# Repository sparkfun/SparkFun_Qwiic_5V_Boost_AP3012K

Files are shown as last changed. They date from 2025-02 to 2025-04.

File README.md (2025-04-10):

SparkFun Qwiic 5V Boost - AP3012K
========================================

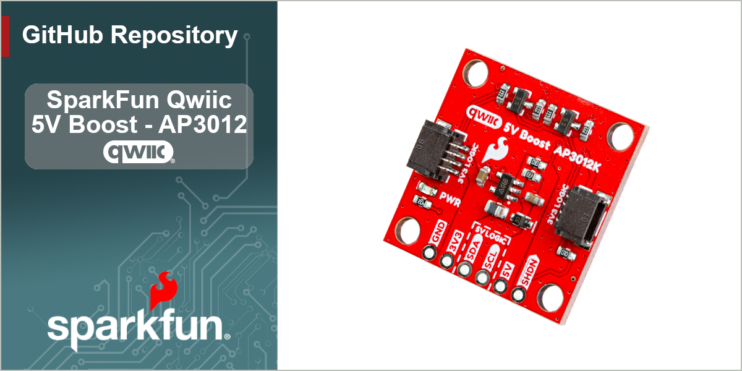
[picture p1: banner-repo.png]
SparkFun Qwiic 5V Boost - AP3012K (https://www.sparkfun.com/sparkfun-qwiic-5v-boost-ap3012k.html)


From its Qwiic connectors, the [SparkFun Qwiic 5V Boost - AP3012K](https://www.sparkfun.com/sparkfun-qwiic-5v-boost-ap3012k.html) converts the **3.3V** logic-level of the I<sup>2</sup>C signals and boosts the **3.3V** power supply; all to **5V** on its [PTH *(plated through-hole)*](https://en.wikipedia.org/wiki/Through-hole_technology) pins. This is handy for connecting any I<sup>2</sup>C device that requires a higher supply voltage for an RGB LED or mechanisms like a DC fan on our air quality sensors:

- [Sensirion SPS30 - Particulate Matter Sensor](https://www.sparkfun.com/particulate-matter-sensor-sps30.html)
- [Sensirion SEN54 - Particle, VOC, Humidity, and Temperature Sensor](https://www.sparkfun.com/particle-voc-humidity-and-temperature-sensor-sen54.html)
- [Sensirion SEN55 - Particle, VOC, NO<sub>x</sub>, Humidity, and Temperature Sensor](https://www.sparkfun.com/sensirion-particle-voc-humidity-and-temperature-sensor-sen55.html)

On the board, we provide `3V3`/`5V` jumpers, which can be used to configure the logic-levels of the I<sup>2</sup>C PTH pins. Therefore, this board can be utilized to connect an I<sup>2</sup>C device that requires any combination of 3.3V/5V for its power and/or signals. Additionally, the [TTL *(transistor–transistor logic)*](https://en.wikipedia.org/wiki/Transistor%E2%80%93transistor_logic) used to convert the logic-levels of the I<sup>2</sup>C signals can also implemented with other types of interfaces; such as a serial bus, similar to our [SparkFun Logic Level Converter - Single Supply](https://www.sparkfun.com/sparkfun-logic-level-converter-single-supply.html).

<hr>

> [!WARNING]
> Soldering is required to connect a 5V I<sup>2</sup>C device to this board.

> [!NOTE]
> The boost circuit on this board is rated to source up to a 100mA at 5V output, with 90% efficiency. However, users should note that this limitation is not only dependent on the load being connected, but also the amount of current that is being sourced to the Qwiic connector system.

Documentation
--------------
- **[Hookup Guide (mkdocs)](http://docs.sparkfun.com/SparkFun_Qwiic_5V_Boost_AP3012K/)** - A hookup guide for the Qwiic 5V Boost - AP3012K, hosted by GitHub pages.<br>
   

  *Need to download or print our hookup guide?*

  - [Print *(Print to PDF)* from Single-Page View](http://docs.sparkfun.com/SparkFun_Qwiic_5V_Boost_AP3012K/print_view)

Repository Contents
-------------------
- **[/docs](/docs/)** - Online documentation files
    - [/assets](/docs/assets/) - Assets files
        - [/3d_model](/docs/assets/3d_model/) - Files for the 3D models
            - [3D CAD Model](/docs/assets/3d_model/cad_model.step) (.step)
        - [/board_files](/docs/assets/board_files/) - Files for the product design
            - [KiCad Design Files](/docs/assets/board_files/kicad_files.zip) (.zip)
            - [Schematic](/docs/assets/board_files/schematic.pdf) (.pdf)
            - [Dimensions](/docs/assets/board_files/dimensions.pdf) (.pdf)
        - [/component_documentation](/docs/assets/component_documentation/) - Datasheets for hardware components
        - [/img/hookup_guide/](/docs/assets/img/hookup_guide/) - Images for hookup guide documentation
- **[/Hardware](/Hardware/)** - Hardware design files (.brd, .sch)
  - **[/Production](/Production/)** - Production files

Product Variants
----------------
- [PRT-28203](https://www.sparkfun.com/sparkfun-qwiic-5v-boost-ap3012k.html) - Initial Release

Version History
---------------
- [v10](https://github.com/sparkfun/SparkFun_Qwiic_5V_Boost_AP3012K/releases/tag/v10) - Initial Release

License Information
-------------------

This product is ***open source***!

Please review the [`LICENSE.md`](./LICENSE.md) file for license information.

If you have any questions or concerns about licensing, please contact technical support on our [SparkFun forums](https://community.sparkfun.com/).

Distributed as-is; no warranty is given.

- Your friends at SparkFun.

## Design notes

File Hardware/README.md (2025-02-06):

SparkFun <PRODUCT NAME> Design Files
=====================================

The .sch and .brd files hare are Eagle CAD schematic and PCB design files from SparkFun Electronics.
A freeware version of Autodesk Eagle can be found [here](https://www.autodesk.com/products/eagle/free-download).

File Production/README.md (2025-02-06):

SparkFun <PRODUCT NAME> Production Files
=========================================

These are the production files SparkFun uses for printing PCBs.

License Information
-------------------
This product is open source! 

The hardware is released under [Creative Commons ShareAlike 4.0 International](https://creativecommons.org/licenses/by-sa/4.0/).

Please use, reuse, and modify these files as you see fit. Please maintain attribution to SparkFun Electronics and release anything derivative under the same license.

Distributed as-is; no warranty is given.

- Your friends at SparkFun.

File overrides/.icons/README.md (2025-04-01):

.icons directory
====================
This folder should contain branding logos for the product documentation

## General Images
- `sfe.svg` - SparkFun flame logo
- `kicad-primary.svg` - Full KiCad logo

## Directory
- `logo` - Other available logos

## SVG Optimizer
- [Remove meta data from svg](https://jakearchibald.github.io/svgomg/)

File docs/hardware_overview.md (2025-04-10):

## :material-folder-cog: Design Files

<!-- Import the component -->
<script type="module" src="https://ajax.googleapis.com/ajax/libs/model-viewer/3.5.0/model-viewer.min.js"></script>

<div class="grid cards desc" markdown>

-   :kicad-primary:{ .enlarge-logo } Design Files

	---

	- :fontawesome-solid-file-pdf: [Schematic](./assets/board_files/schematic.pdf)
	- :material-folder-zip: [KiCad Files](./assets/board_files/kicad_files.zip)
	- :material-rotate-3d: [STEP File](./assets/3d_model/cad_model.step)
	- :fontawesome-solid-file-pdf: [Board Dimensions](./assets/board_files/dimensions.pdf):
		- 1.00" x 1.00" (25.40mm x 25.40mm)

-   <!-- Boxes in tabs -->

	=== "3D Model"
		<center>
		<model-viewer src="../assets/3d_model/web_model.glb" camera-controls poster="../assets/3d_model/poster.png" tone-mapping="neutral" shadow-intensity="1.7" exposure="0.8" environment-image="legacy" shadow-softness="0.7" camera-orbit="3.797e-14deg 35deg 0.07345m" field-of-view="30deg" style="width: 100%; height: 450px;">
		</model-viewer>

		[Download the `*.step` File](./assets/3d_model/cad_model.step "Click download"){ .md-button .md-button--primary width="250px" }

		</center>

		???+ tip "Manipulate 3D Model"
			<center>

			| Controls       | Mouse                    | Touchscreen    |
			| :------------- | :----------------------: | :------------: |
			| Zoom           | Scroll Wheel             | 2-Finger Pinch |
			| Rotate         | ++"Left-Click"++ & Drag  | 1-Finger Drag  |
			| Move/Translate | ++"Right-Click"++ & Drag | 2-Finger Drag  |

			</center>

	=== "Dimensions"
		<center>
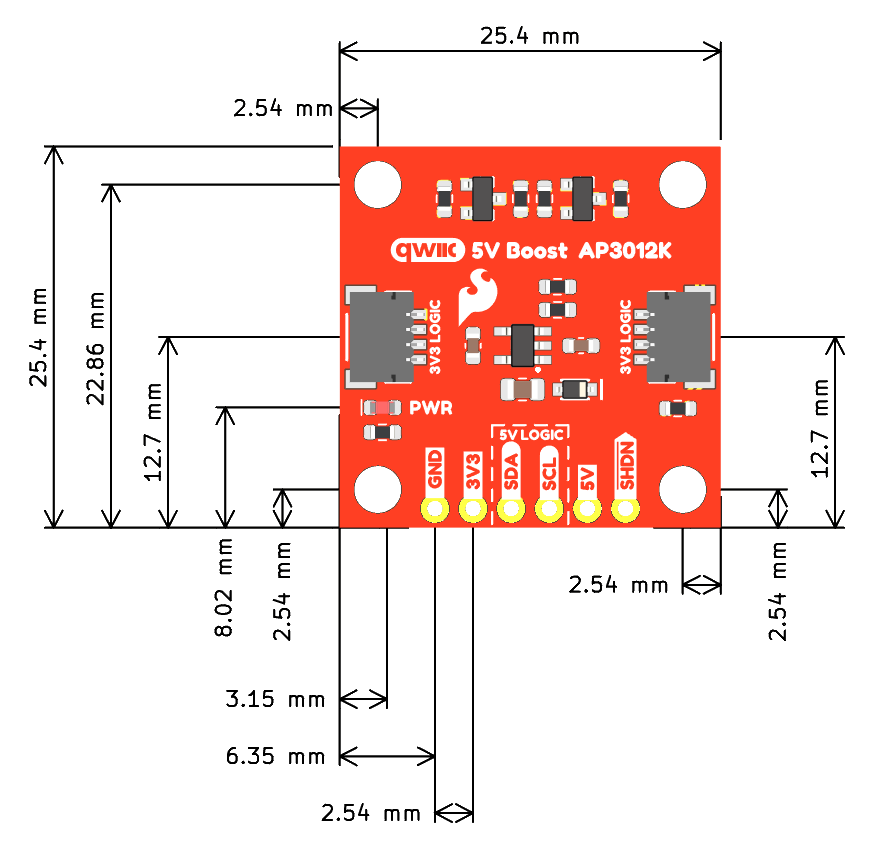
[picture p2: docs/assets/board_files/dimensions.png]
Board Dimensions
		
		<figcaption markdown>
		Dimensions of the Qwiic 5V Boost.
		</figcaption>
		</center>

		???+ tip "Need more measurements?"
			For more information about the board's dimensions, users can download the [KiCad files](./assets/board_files/kicad_files.zip) for this board. These files can be opened in KiCad and additional measurements can be made with the measuring tool.

			!!! info ":octicons-download-16:{ .heart } KiCad - Free Download!"
				KiCad is free, open-source [CAD]("computer-aided design") program for electronics. Click on the button below to download their software. *(\*Users can find out more information about KiCad from their [website](https://www.kicad.org/).)*

				<center>
				[Download :kicad-primary:{ .enlarge-logo }](https://www.kicad.org/download/ "Go to downloads page"){ .md-button .md-button--primary width="250px" }
				</center>

			???+ info ":straight_ruler: Measuring Tool"
				This video demonstrates how to utilize the dimensions tool in KiCad, to include additional measurements:

				<center>
				<article class="video-500px">
				<iframe src="https://www.youtube.com/embed/-eXuD8pkCYw" title="KiCad Dimension Tool" frameborder="0" allow="accelerometer; autoplay; clipboard-write; encrypted-media; gyroscope; picture-in-picture" allowfullscreen></iframe>
				</article>
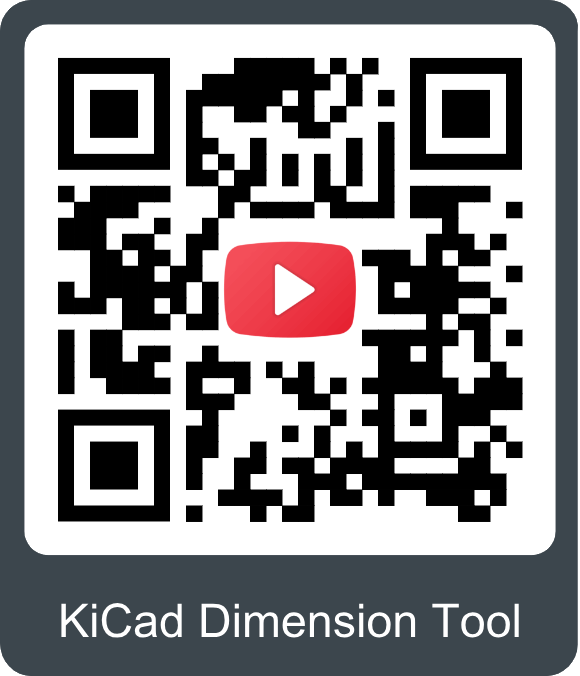
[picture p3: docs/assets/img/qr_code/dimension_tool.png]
QR code to play video
				
				</center>

</div>

## Board Layout

<div class="grid" markdown>

<div markdown>

<figure markdown>
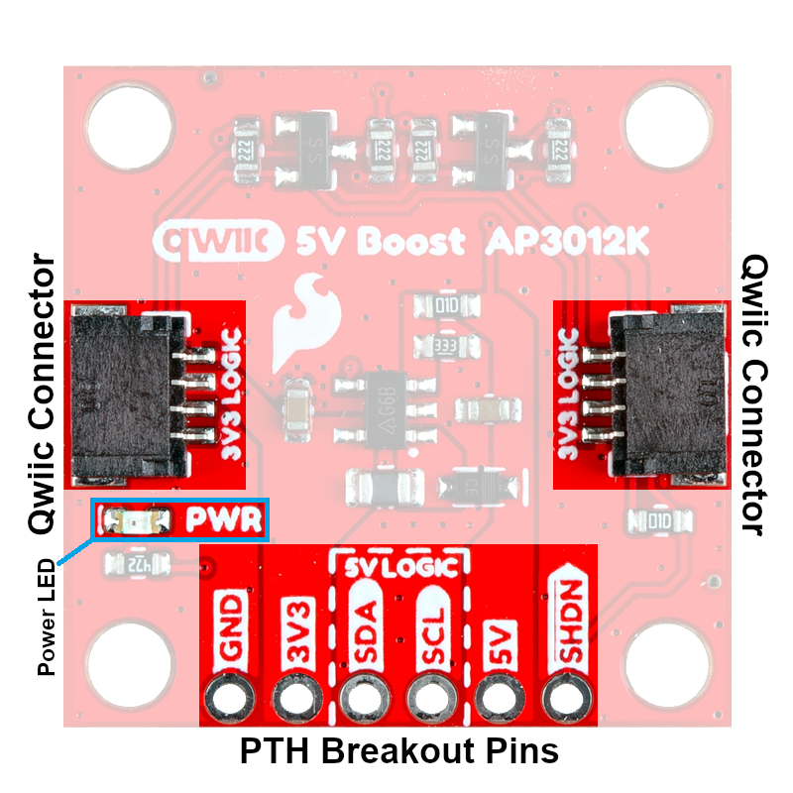
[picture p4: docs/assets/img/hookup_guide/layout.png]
Layout

<figcaption markdown>Layout of the major components on the Qwiic 5V Boost.</figcaption>
</figure>

</div>

<div markdown>

The Qwiic 5V Boost has the following features:

1. **[PTH Breakout Pins](#breakout-pins)**
:	A set of six 0.1" pitch [PTH](https://en.wikipedia.org/wiki/Through-hole_technology "Plated Through Hole") pins that breakout the boosted power and converted [TTL](https://en.wikipedia.org/wiki/Transistor%E2%80%93transistor_logic "Transistor–Transistor Logic") signals of the I^2^C bus; and a control pin for the boost converter.
1. **[Qwiic Connectors](#qwiic-connectors)**
:	The primary interfaces for the Qwiic 5V Boost, these are pass-through connectors for the I^2^C bus.
1. **[`PWR` LED](#led)**
:	A red indication LED for when the board is supplied with 3.3V.

</div>

</div>

## Breakout Pins
The [PTH](https://en.wikipedia.org/wiki/Through-hole_technology "Plated Through Hole") pins of the Qwiic 5V Boost breakout: the 3.3V power supply from the [Qwiic connectors](#qwiic-connectors) that supplies power to the AP3012, the boosted 5V power output from the AP3012, a control pin to disable the AP3012, and the converted 5V, logic-level I^2^C signals from the [Qwiic connectors](#qwiic-connectors).

<div class="grid" markdown>

<div markdown>

<figure markdown>
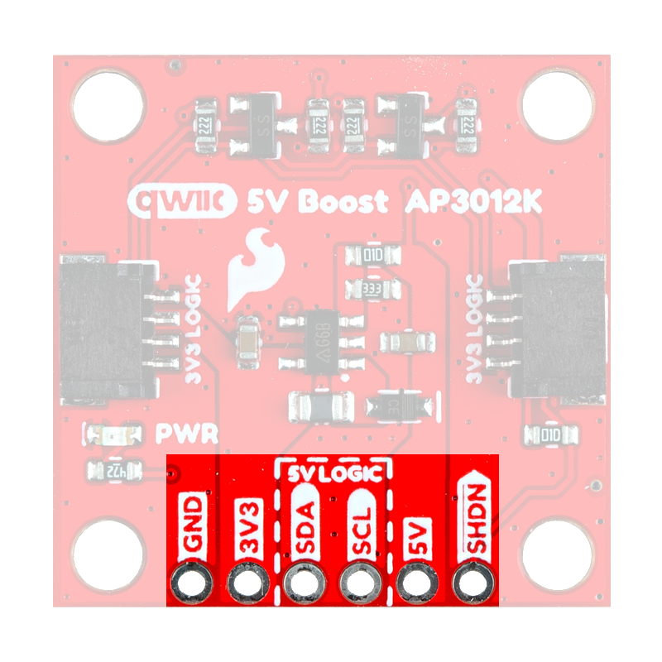
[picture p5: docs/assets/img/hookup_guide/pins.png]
Flipped pins

<figcaption markdown>Pin connections between the top and bottom of the Qwiic 5V Boost.</figcaption>
</figure>

</div>

<div markdown>

`GND`
:	The common ground or the 0V reference for the voltage supplies.

`3V3`
:	The same 3.3V operating power for the Qwiic connectors.

`SDA`/`SCL`
:	The converted [TTL](https://en.wikipedia.org/wiki/Transistor%E2%80%93transistor_logic "Transistor–Transistor Logic") signals of the I^2^C pins from the [Qwiic connectors](#qwiic-connectors); their converted logic-level is controlled by the `3V3`/`5V` [jumpers](#jumpers).

`5V`
:	The boost 5V power output from the AP3012 boost converter, which is rated up to ~100mA load.

<span style="text-decoration:overline">`SHDN`</span>
:	The control signal for AP3012 boost converter; pull `LOW` to disable the IC.

</div>

</div>

!!! info "I/O Configurations"
	With the [`3V3`/`5V` jumpers](#jumpers) to configure the logic-levels of the I^2^C [PTH](https://en.wikipedia.org/wiki/Through-hole_technology "Plated Through Hole") pins, users can convert the power and logic-levels of the Qwiic connector to any combination of 3.3V and/or 5V on the PTH pins:

	<center>

	<table markdown>
	<tr>
	<th>Output Power</th>
	<td>5V</td>
	<td>5V</td>
	<td>3.3V</td>
	</tr>
	<tr markdown>
	<th markdown>I^2^C Logic-Level</th>
	<td>3.3V</td>
	<td>5V</td>
	<td>5V</td>
	</tr>
	</table>

	</center>

	*By default, the pins are configured to a 5V logic-level.*

???+ danger "Maximum Load Current"
	We recommend a maximum load current of ~100mA from the `5V` output supply voltage from the AP3012 boost converter.

	The boosted supply voltage of the boost converter will begin to drop as the current draw from the load increases. We found that for a boosted 5V output from a 3.3V input voltage, there is an inflection point around **100mA** where the boosted voltage begins to drop off significantly.

	<center>

	| Load Current | Boosted Voltage |
	| :----------: | :-------------: |
	| 10mA | 4.92V |
	| 20mA | 4.91V |
	| 75mA | 4.90V |
	| 100mA | 4.89V |
	| 150mA | 4.87V |
	| 200mA | 4.65V |

	</center>

	!!! info
		This limitation is driven by the current load and supply current for the Qwiic connect system. It is not dictated by the junction temperature of the AP3012.

## Qwiic Connectors
Qwiic connectors are provided for users to seamlessly integrate with [SparkFun's Qwiic Ecosystem](https://www.sparkfun.com/qwiic). These are pass-through connectors that operate at the standard 3.3V operating voltage and logic-levels.

<figure markdown>
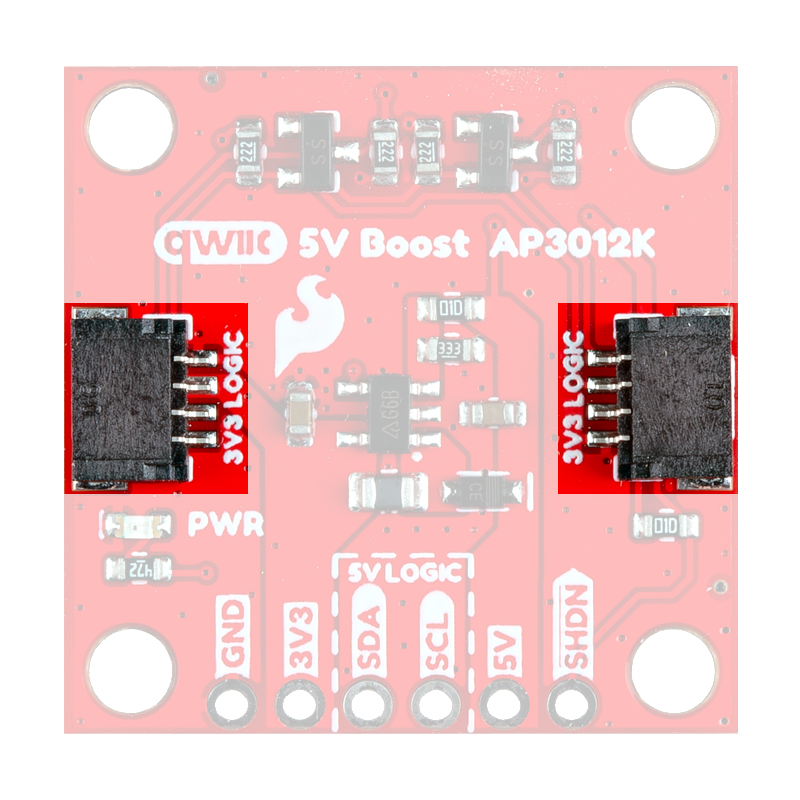
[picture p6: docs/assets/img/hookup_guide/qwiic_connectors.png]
Qwiic connectors

<figcaption markdown>Qwiic connectors on the Qwiic 5V Boost.</figcaption>
</figure>

???+ tip "What is Qwiic?"

	<div class="grid" markdown>

	<div markdown>

	<!-- Qwiic Banner -->
	<center>
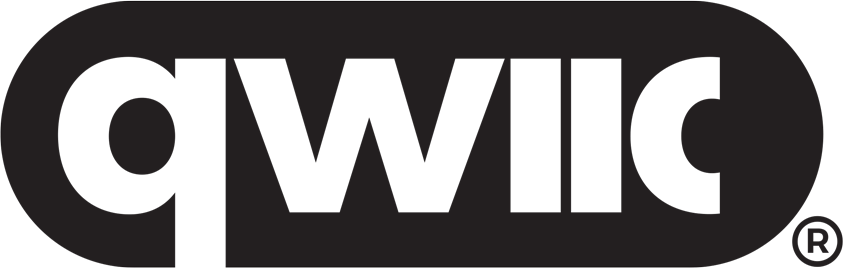
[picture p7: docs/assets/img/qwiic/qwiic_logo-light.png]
Qwiic Logo - light theme (https://www.sparkfun.com/qwiic)
	
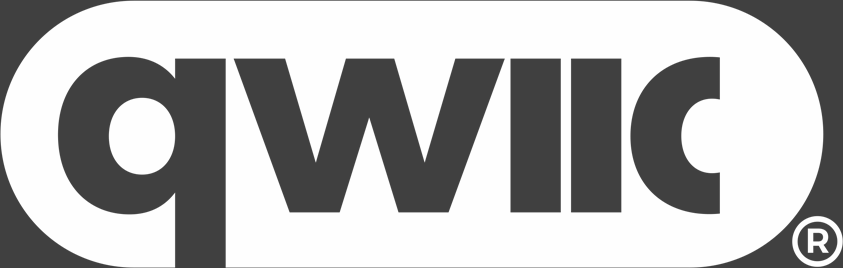
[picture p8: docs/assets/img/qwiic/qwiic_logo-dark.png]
Qwiic Logo - dark theme (https://www.sparkfun.com/qwiic)
	
	</center>

	---

	The [Qwiic connect system](https://www.sparkfun.com/qwiic) is a solderless, polarized connection system that allows users to seamlessly daisy chain I^2^C boards together. Play the video, to learn more about the Qwiic connect system or click on the banner above to learn more about [Qwiic products](https://www.sparkfun.com/qwiic).

	</div>

	<div style="max-height=400px;" markdown>

	<center>
	<div class="video-container">
	<iframe src="https://www.youtube.com/embed/x0RDEHqFIF8" title="SparkFun's Qwiic Connect System" frameborder="0" allow="accelerometer; encrypted-media; gyroscope; picture-in-picture" allowfullscreen></iframe>
	</div>
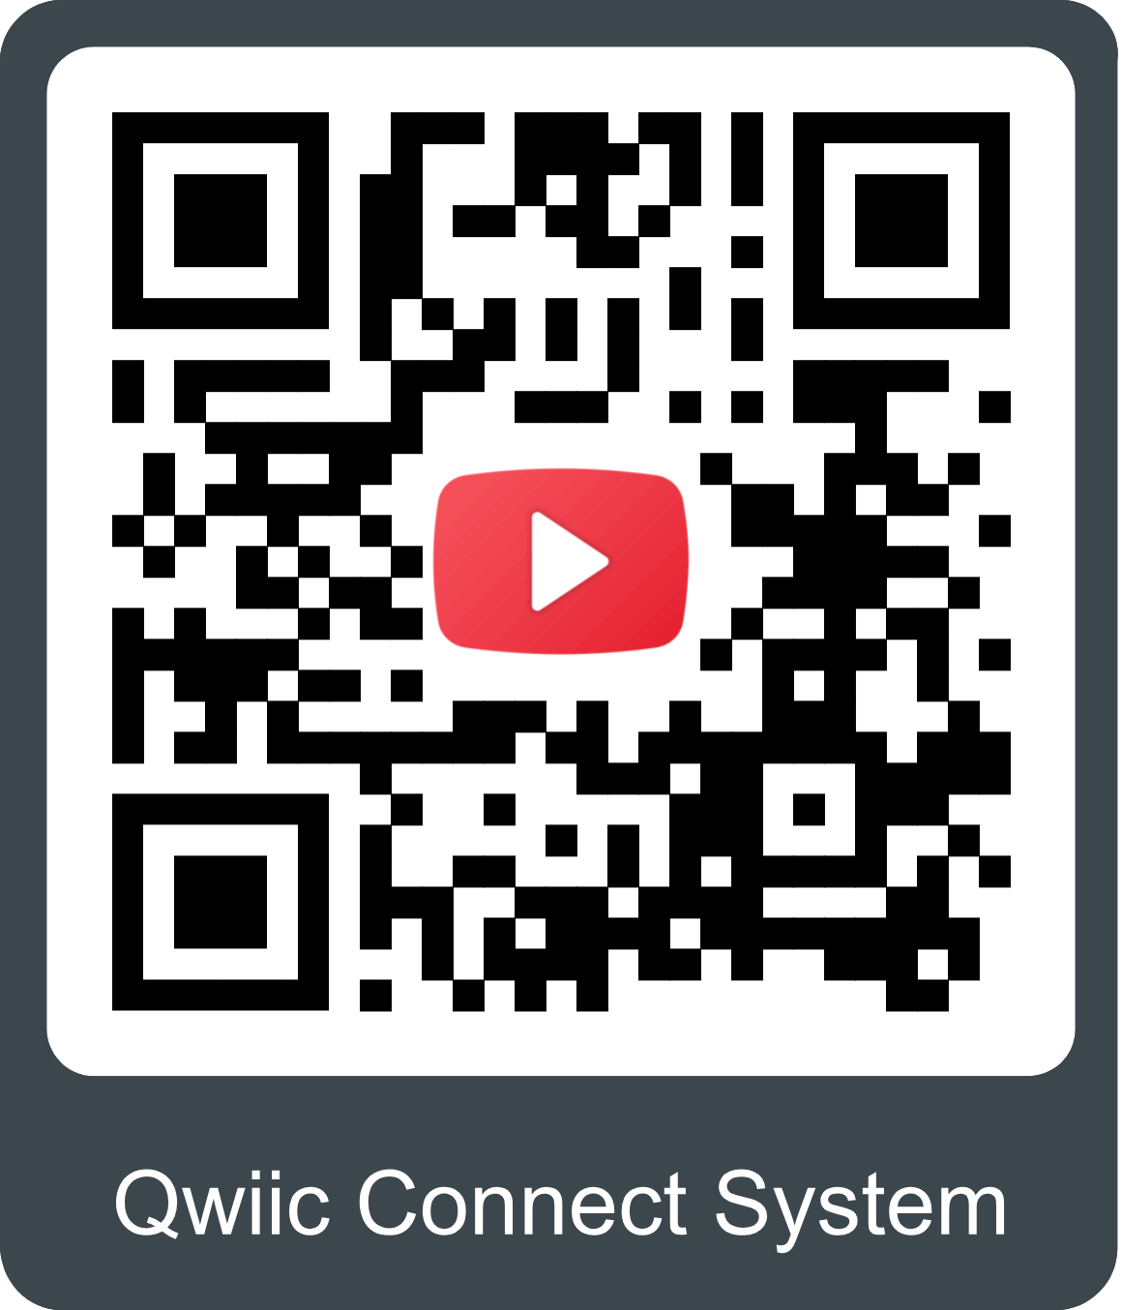
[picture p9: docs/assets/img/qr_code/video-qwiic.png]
QR code to instructional video
	
	</center>

	</div>

	</div>

	!!! info "Features of the Qwiic System"

		=== "No Soldering"

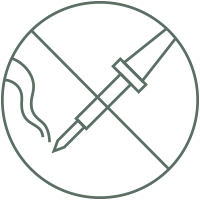
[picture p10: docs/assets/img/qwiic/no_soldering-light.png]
no soldering - light theme
			
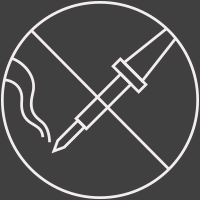
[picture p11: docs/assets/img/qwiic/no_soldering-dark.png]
no soldering - dark theme
			

			Qwiic cables (4-pin JST) plug easily from development boards to sensors, shields, accessory boards and more, making easy work of setting up a new prototype.

		=== "Polarized Connector"

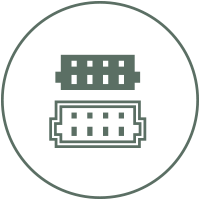
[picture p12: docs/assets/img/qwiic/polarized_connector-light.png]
polarized connector - light theme
			
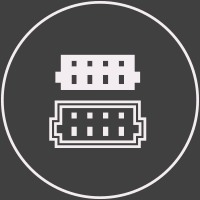
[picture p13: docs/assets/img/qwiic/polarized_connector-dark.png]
polarized connector - dark theme
			

			There's no need to worry about accidentally swapping the `SDA` and `SCL` wires on your breadboard. The Qwiic connector is polarized so you know you’ll have it wired correctly every time.

			The part numbers for the PCB connector is `SM04B-SRSS` ([Datasheet](https://cdn.sparkfun.com/assets/parts/1/2/2/8/9/Qwiic_Connector_Datasheet.pdf)) and the mating connector on the cables is `SHR04V-S-B`; or an equivalent *1mm pitch, 4-pin JST connection*.

		=== "Daisy Chain-able"

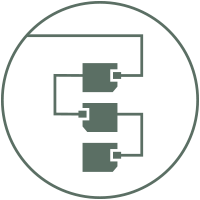
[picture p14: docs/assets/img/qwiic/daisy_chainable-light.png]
daisy chainable - light theme
			
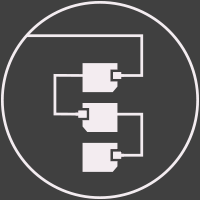
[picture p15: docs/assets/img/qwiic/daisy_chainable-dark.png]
daisy chainable - dark theme
			

			It’s time to leverage the power of the I^2^C bus! Most Qwiic boards will have two or more connectors on them, allowing multiple devices to be connected.

## LED
There is a red `PWR` LED to indicate when the Qwiic 5V Boost is powered with 3.3V. The LED can be disabled by cutting the `LED` [jumper](#jumpers).

<figure markdown>
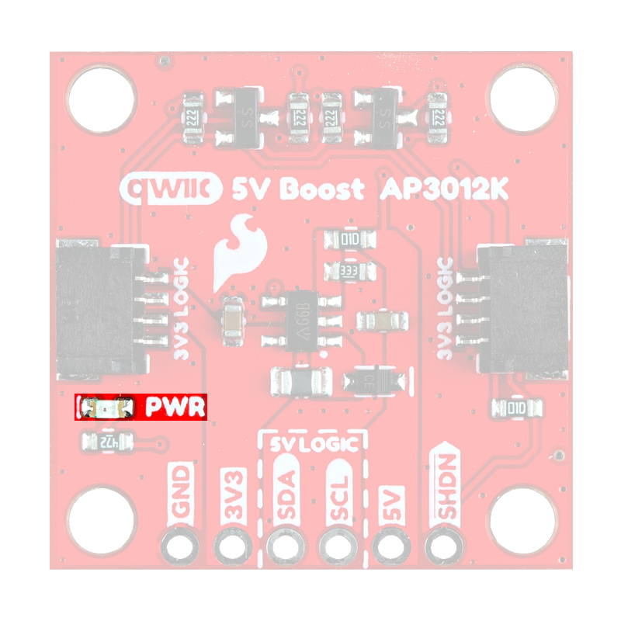
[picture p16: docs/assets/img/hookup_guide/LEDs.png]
LED

<figcaption markdown>The red `PWR` LED the Qwiic 5V Boost.</figcaption>
</figure>

## Jumpers
There are four jumpers on the back of the board that can be used to easily modify the hardware connections on the board.

<div class="grid" markdown>

<div markdown>

<figure markdown>
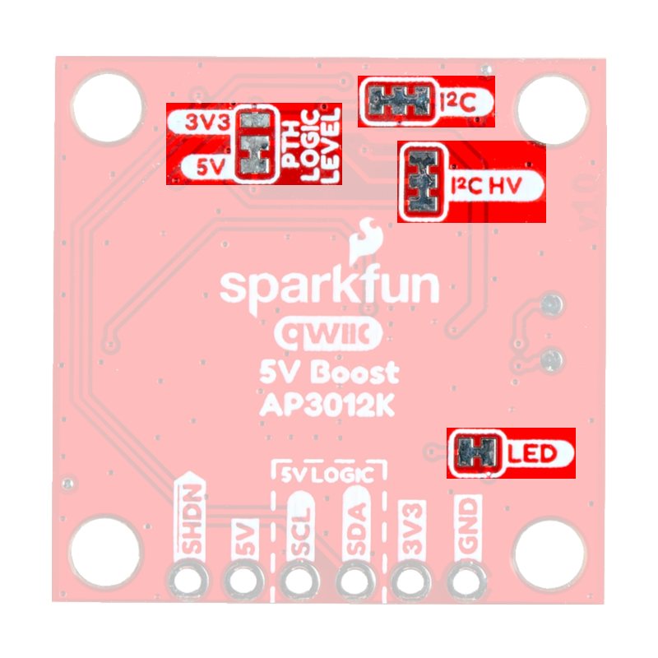
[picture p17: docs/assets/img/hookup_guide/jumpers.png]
Jumpers

<figcaption markdown>The jumpers on the top of the Qwiic 5V Boost.</figcaption>
</figure>

</div>

<div markdown>

`I2C`
:	This jumper can be cut to disconnect the pull-up resistors from the I^2^C pins of Qwiic connectors.

`I2C HV`
:	This jumper can be cut to disconnect the pull-up resistors from the I^2^C pins of [PTH](https://en.wikipedia.org/wiki/Through-hole_technology "Plated Through Hole") breakout pins.

`LED`
:	This jumper can be cut to remove power from the red `PWR` LED.

`3V3`/`5V`
:	Configures the [TTL](https://en.wikipedia.org/wiki/Transistor%E2%80%93transistor_logic "Transistor–Transistor Logic") signal level for the I^2^C pins of [PTH](https://en.wikipedia.org/wiki/Through-hole_technology "Plated Through Hole") breakout pins to either **5V** or **3.3V**.

</div>

</div>

???+ note "Never modified a jumper before?"
	Check out our <a href="https://learn.sparkfun.com/tutorials/664">Jumper Pads and PCB Traces tutorial</a> for a quick introduction!

	<article class="grid cards" markdown align="center">

	-   <a href="https://learn.sparkfun.com/tutorials/664">
		<figure markdown>
		Tutorial thumbnail
		</figure>

		---

		**How to Work with Jumper Pads and PCB Traces**</a>

	</article>

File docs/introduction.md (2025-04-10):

<figure markdown>
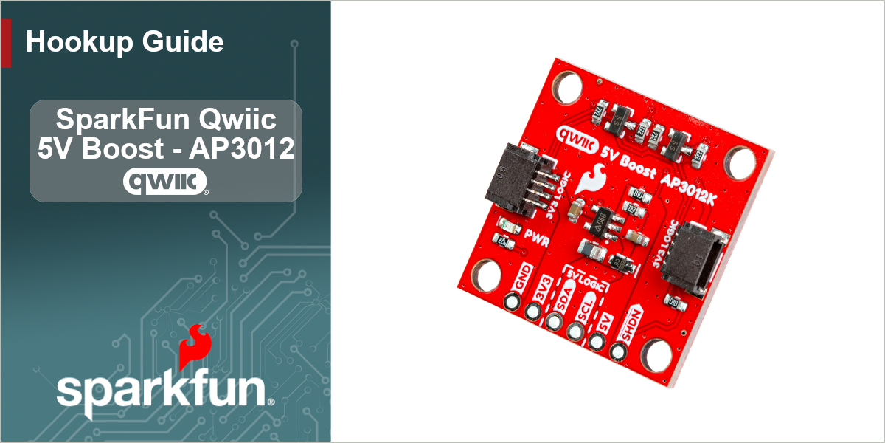
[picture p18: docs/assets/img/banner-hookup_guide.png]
Hookup Guide - Thumbnail

</figure>

---

# Introduction

The SparkFun Qwiic 5V Boost - AP3012K converts the logic-level and boost the power of the Qwiic connect system from **3.3V**, to **5V** on its [PTH](https://en.wikipedia.org/wiki/Through-hole_technology "Plated Through-Hole") pins. This is handy for connecting any I<sup>2</sup>C device that requires a higher supply voltage, such as super bright LEDs or mechanisms like a DC fan on our air quality sensors. On the board, we also provide `3V3`/`5V` jumpers, which can be used to configure the logic-levels of the I<sup>2</sup>C PTH pins. Therefore, this board can be utilized to connect an I<sup>2</sup>C device that requires any combination of 3.3V/5V for its power and/or signals.

???+ note
	The boost circuit on this board is rated to source up to a 100mA at 5V output, with 90% efficiency. However, users should note that this limitation is not only dependent on the load being connected, but also the amount of current that is being sourced to the Qwiic connector system.

---

In this guide we'll cover how to utilize the Qwiic 5V Boost with two 5V I^2^C devices; such as the [BlinkM LED](https://www.sparkfun.com/blinkm-i2c-controlled-rgb-led.html) and [Sensirion SEN55 sensor](https://www.sparkfun.com/sensirion-particle-voc-humidity-and-temperature-sensor-sen55.html). To follow along with this tutorial, users will need the following items:

- [Thing Plus Development Board](https://www.sparkfun.com/thing-plus)
	- We recommend either the [ESP32 Thing Plus](https://www.sparkfun.com/sparkfun-thing-plus-esp32-wroom-usb-c.html) or the [RP2350 Thing Plus](https://www.sparkfun.com/sparkfun-thing-plus-rp2350.html)
- [SparkFun Qwiic 5V Boost - AP3012K](https://www.sparkfun.com/sparkfun-qwiic-5v-boost-ap3012k.html)
- [SparkFun Qwiic Cable Kit](https://www.sparkfun.com/sparkfun-qwiic-cable-kit.html)
- A 5V compatible I^2^C device:
	- [BlinkM - I2C Controlled RGB LED](https://www.sparkfun.com/blinkm-i2c-controlled-rgb-led.html)
	- [Sensirion SEN55 - Particle, VOC, NO~x~, Humidity, and Temperature Sensor](https://www.sparkfun.com/sensirion-particle-voc-humidity-and-temperature-sensor-sen55.html)
- Soldering tools
- Headers and jumper Wire
- USB cable

???+ warning
	Soldering is required for this board.

???+ tip
	The particulate matter sensor requires an extra `GND` connection to enable the I^2^C interface.

???+ note
	These other Sensirion particulate matter sensors, may also be used in place of the SEN55:

	- [Sensirion SPS30 - Particulate Matter Sensor](https://www.sparkfun.com/particulate-matter-sensor-sps30.html)
	- [Sensirion SEN54 - Particle, VOC, Humidity, and Temperature Sensor](https://www.sparkfun.com/particle-voc-humidity-and-temperature-sensor-sen54.html)

## Topics
This document contains two main sections: **Quickstart Guide** and **Hardware** sub-sections.

- The **Quickstart Guide** assumes a working knowledge of development boards and the required software to program them for your project's needs. It covers the basic hardware information and assembly instructions users would need to get started with this product.
- The **Hardware** sections provide:
	- An overview of the Qwiic 5V Boost - AP3012K board and its major components. Refer to this page for information on the connectors, breakout pins, and jumpers.
	- Assembly instructions to utilize this product with compatible 5V I^2^C devices.

## Resources and Support
You'll find the board design files (KiCad files & schematic), relevant documentation (datasheets, white papers, etc.) and other helpful links on the [Resources page](./resources.md). Lastly, the **Support** section includes a [Troubleshooting page](./troubleshooting_tips.md) that includes any helpful tips specific to this board as well as information on how to receive technical support from SparkFun.

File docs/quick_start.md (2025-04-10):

<figure markdown>
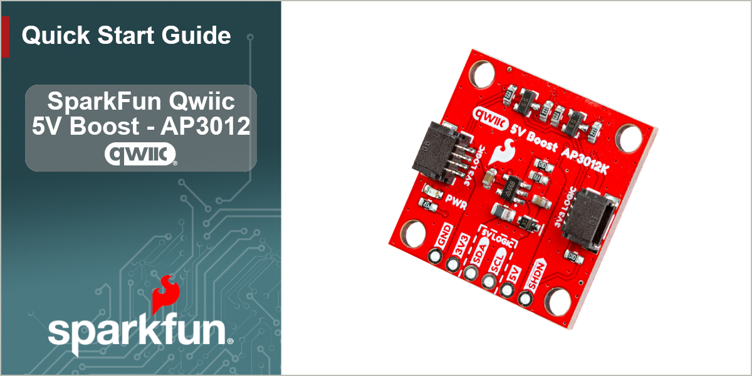
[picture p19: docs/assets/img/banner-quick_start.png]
Quick Start Guide - Thumbnail

</figure>

---

--8<-- "./introduction.md:19:34"

## Board Layout
This is the basic layout of the Qwiic 5V Boost board.

<!-- Board Layout -->
--8<-- "hardware_overview.md:83:86"

## Demo - BlinkM LED
In this demo, we'll connect a BlinkM RGB LED to the Qwiic 5V Boost board; and control it with an ESP32 Thing Plus development board, utilizing the Arduino IDE.

### Connect the BlinkM LED
Soldering is required to connect the BlinkM LED to the Qwiic 5V Boost board. In the example below, we used headers and jumper wires to make the necessary pin connections shown in the table. Once the BlinkM LED is attached, users will need to connect the Qwiic 5V Boost board to their development board with a Qwiic cable.

<div class="grid" markdown>

<div markdown align="center">

| Qwiic 5V Boost | BlinkM RGB LED |
| :---: | :---: |
| `GND` | `-` |
| `5V`  | `+` |
| `SDA` | `d` |
| `SCL` | `c` |

</div>

<div markdown>

<figure markdown>
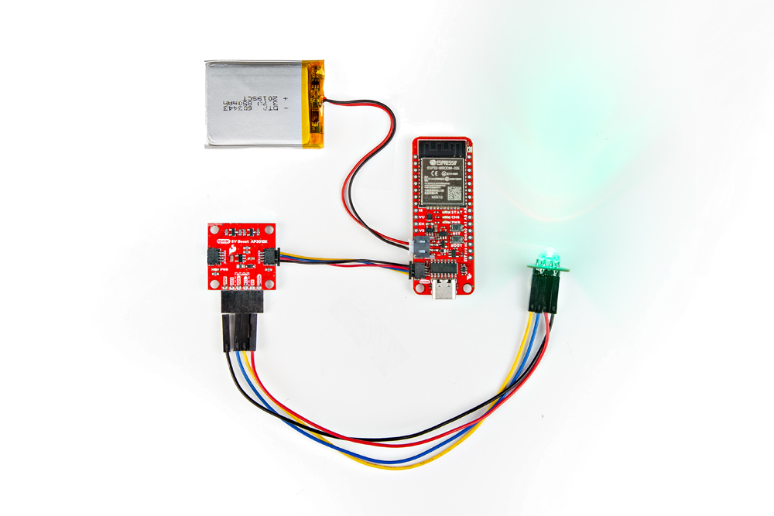
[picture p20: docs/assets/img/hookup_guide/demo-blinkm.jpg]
Demo - BlinkM LED

<figcaption markdown>Connecting the BlinkM LED to the Qwiic 5V Boost.</figcaption>
</figure>

</div>

</div>

???+ tip
	If you're not familiar with using breakout board or soldering, please refer to the Hardware [Overview](./hardware_overview.md) & [Assembly](./hardware_assembly.md) sections for a detailed overview of the board along with instructions on soldering to the breakout.

### Example Code
With the hardware assembled, users will need to program their development board to control the BlinkM LED. In the Arduino IDE, upload the [`BlinkMStart` example](https://github.com/todbot/BlinkM-Arduino/blob/main/examples/BlinkMStart/BlinkMStart.ino) sketch from the [BlinkM Arduino library](https://github.com/todbot/BlinkM-Arduino). This example will fade the hue of the BlinkM LED and output the hue values to the Serial Monitor.

Follow the steps below to upload the example code:

- Open the [Arduino IDE](https://docs.arduino.cc/software/ide-v2/tutorials/getting-started-ide-v2/).
- Manually install the BlinkM Arduino library, by downloading it from the [GitHub repository](https://github.com/todbot/BlinkM-Arduino).
- Restart the Arduino IDE.
- Open `BlinkMStart` example sketch from the BlinkM Arduino library.
- Select your board and serial port; then, upload the sketch.
- Once the code compiles and uploads to the development board, open the [serial monitor](https://docs.arduino.cc/software/ide-v2/tutorials/ide-v2-serial-monitor/) with the baud rate set to **9600** bps.
- The example sketch prints out the hue values as they change on the BlinkM LED.

???+ tip
	If you're not familiar with using the Arduino IDE, refer to the [Troubleshooting Tips](./troubleshooting_tips.md) section for related tutorials.

!!! tip "LED Not Changing"
	For users who find it hard to distinguish the changes in the LED's hue, the sketch can be modified to change the RGB values. Below, is an example of modifications that would change the `red` value of the RGB LED.

	???+ code "Modifications"

		```cpp linenums="15" hl_lines="1"
		byte red=0;
		```	
		```cpp linenums="36" hl_lines="3 5 7"
		void loop() 
		{
		    red += 10; // random(0,255);
		    Serial.print("Fading to hue ");
		    Serial.println(red);
		
		    blinkm.fadeToRGB( red, 255, 255);
		
		    delay(500);
		}
		```

#### Source Files

- [BlinkM Arduino library](https://github.com/todbot/BlinkM-Arduino)
- [`BlinkMStart.ino` example sketch](https://github.com/todbot/BlinkM-Arduino/blob/main/examples/BlinkMStart/BlinkMStart.ino)

	???+ code "BlinkMStart.ino"
		```cpp linenums="1"
		--8<-- "https://github.com/todbot/BlinkM-Arduino/raw/refs/heads/main/examples/BlinkMStart/BlinkMStart.ino"
		```

## Demo - SEN55 Particle Sensor
In this demo, we'll connect the Sensirion SEN55 particulate matter, VOC, NO~x~, humidity, and temperature sensor to the Qwiic 5V Boost board; and read data from it with an ESP32 Thing Plus development board, utilizing the Arduino IDE.

### Connect the Sensirion SEN55 Sensor
Soldering is required to connect the SEN55 sensor to the Qwiic 5V Boost board. In the example below, we used headers and a Qwiic jumper cable to make the necessary pin connections shown in the tables.

<div class="grid" markdown>

<div markdown align="center">

| Qwiic 5V Boost | Sensirion SEN55 Sensor |
| :---: | :---: |
| `GND` | `2` |
| `5V`  | `1` |
| `SDA` | `3` |
| `SCL` | `4` |
| `GND` | `5` |

</div>

<div markdown>

<figure markdown>
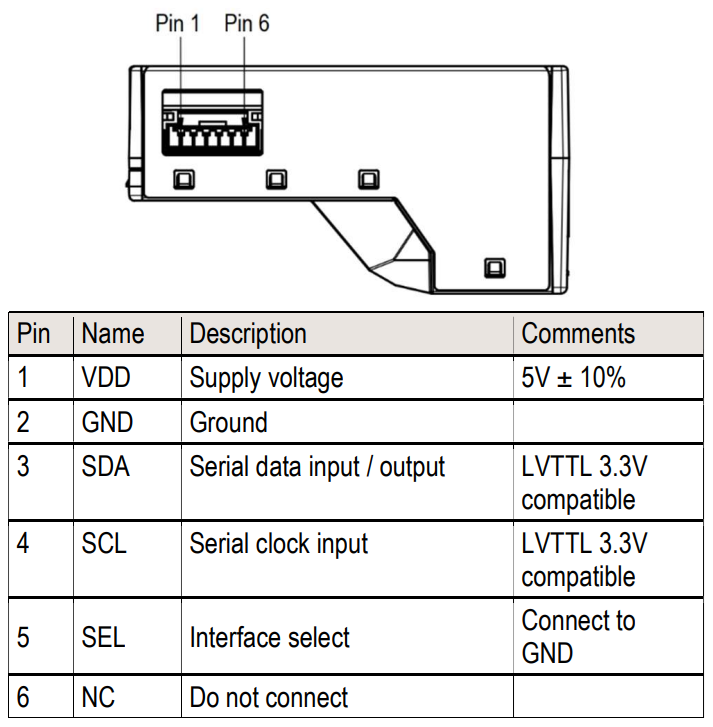
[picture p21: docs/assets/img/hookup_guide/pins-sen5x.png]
SEN55 sensor pins

<figcaption markdown>Hardware pins for the Sensirion SEN55 sensor.</figcaption>
</figure>

</div>

</div>

Once the sensor is attached, users will need to connect the Qwiic 5V Boost board to their development board with a Qwiic cable.

<figure markdown>
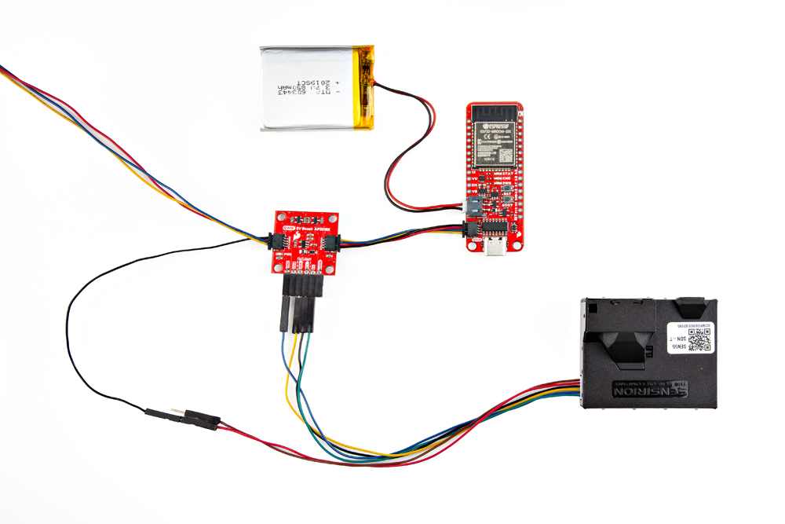
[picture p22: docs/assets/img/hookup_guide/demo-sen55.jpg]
Demo - SEN55 sensor

<figcaption markdown>Connecting the Sensirion SEN55 sensor to the Qwiic 5V Boost.</figcaption>
</figure>

???+ tip
	If you're not familiar with using breakout board or soldering, please refer to the Hardware [Overview](./hardware_overview.md) & [Assembly](./hardware_assembly.md) sections for a detailed overview of the board along with instructions on soldering to the breakout.

### Example Code
With the hardware assembled, users will need to program their development board to retrieve data from the SEN5X sensor. In the Arduino IDE, upload the [`exampleUsage` example](https://github.com/Sensirion/arduino-i2c-sen5x/blob/master/examples/exampleUsage/exampleUsage.ino) sketch from the [Sensirion I2C SEN5X Arduino library](https://github.com/Sensirion/arduino-i2c-sen5x). This example will read the particulate matter, VOC, NO~x~, humidity, and temperature values from the SEN5X sensor and output them in the Serial Monitor.

Follow the steps below to upload the example code:

- Open the [Arduino IDE](https://docs.arduino.cc/software/ide-v2/tutorials/getting-started-ide-v2/).
- Open the [Library Manager](https://docs.arduino.cc/software/ide-v2/tutorials/ide-v2-installing-a-library/) tool, search for the `Sensirion I2C SEN5X` Arduino library and install the latest version.
- Open `exampleUsage` example sketch from the Sensirion I2C SEN5X Arduino library.
- Select your board and serial port; then, upload the sketch.
- Once the code compiles and uploads to the development board, open the [serial monitor](https://docs.arduino.cc/software/ide-v2/tutorials/ide-v2-serial-monitor/) with the baud rate set to **115200** bps.
- The example sketch prints out the particulate matter, VOC, NO~x~, humidity, and temperature values from the SEN55 sensor.

???+ tip
	If you're not familiar with using the Arduino IDE, refer to the [Troubleshooting Tips](./troubleshooting_tips.md) section for related tutorials.

#### Source Files

- [Sensirion SEN5X Arduino library](https://github.com/Sensirion/arduino-i2c-sen5x)
- [`exampleUsage.ino` example sketch](https://github.com/Sensirion/arduino-i2c-sen5x/blob/master/examples/exampleUsage/exampleUsage.ino)

	???+ code "exampleUsage.ino"
		```cpp linenums="1"
		--8<-- "https://github.com/Sensirion/arduino-i2c-sen5x/raw/refs/heads/master/examples/exampleUsage/exampleUsage.ino"
		```

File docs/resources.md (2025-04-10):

## Product Resources

- :sfe: [Product Page](https://www.sparkfun.com/sparkfun-qwiic-5v-boost-ap3012k.html)
- :material-folder-cog: Design Files:
	- :fontawesome-solid-file-pdf: [Schematic](./assets/board_files/schematic.pdf)
	- :fontawesome-solid-file-pdf: [Board Dimensions](./assets/board_files/dimensions.pdf)
	- :material-folder-zip: [KiCad Files](./assets/board_files/kicad_files.zip)
	- :material-cube-outline: [STEP File](./assets/3d_model/cad_model.step)
- Component Documentation:
	- :fontawesome-solid-file-pdf: [AP3012 Datasheet](https://www.diodes.com/datasheet/download/AP3012.pdf)
	- :fontawesome-solid-file-pdf: [AP3012K EVB User Guide](https://www.diodes.com/assets/Evaluation-Boards/AP3012K-EVB-User-Guide.pdf)
- :material-youtube: [SFE Product Showcase Video]()
- :material-github: [Hardware Repo](https://github.com/sparkfun/SparkFun_Qwiic_5V_Boost_AP3012K)

## :sfe: Additional Resources

- :sfe: [Qwiic Connect System](https://www.sparkfun.com/qwiic)
- :material-account-supervisor: [SparkFun Technical Assistance](https://www.sparkfun.com/technical_assistance)

## 🏭 Manufacturer's Resources
Diodes Incorporated also provides great resources for the AP3012 Buck Regulator:

- [Product Page](https://www.diodes.com/part/view/AP3012/)
	- :material-file-document-multiple: [Technical Documentation](https://www.diodes.com/part/view/AP3012/#section-details)
- :material-head-question: [Technical Support Page](https://www.diodes.com/about/contact-us/technical-support/)

<!-- QR Code for Hookup Guide (Displayed when printed) -->
<center>
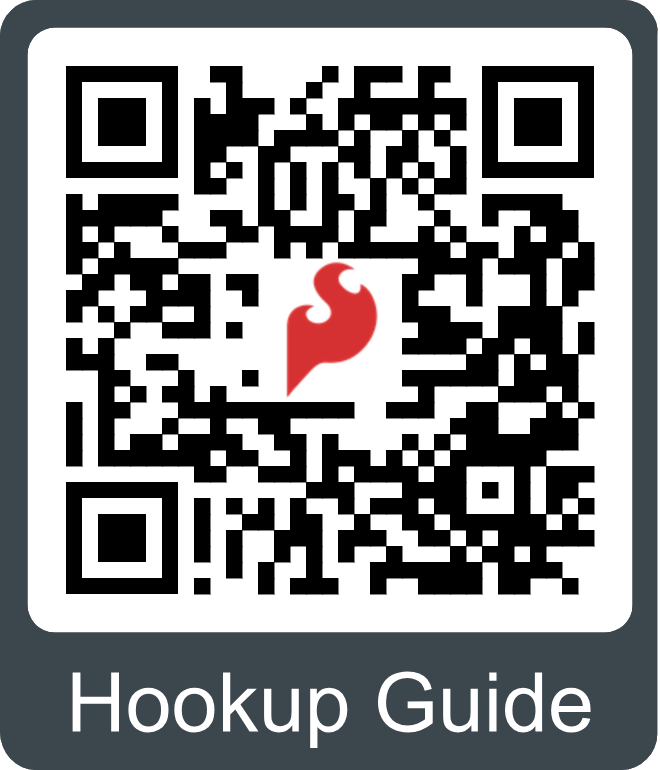
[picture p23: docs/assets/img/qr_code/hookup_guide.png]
QR code to the hookup guide

</center>

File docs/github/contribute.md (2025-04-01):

# Contribute: Make an Augmentation!
Spot an improvement opportunity? Feel free to contribute to our open-source design and documentation. 

## :material-file-document-multiple:&nbsp;Improve our Documentation
All of this documentation can be modified by you! Please help us make it better.

- These pages are contained in the [`docs` folder](https://github.com/sparkfun/SparkFun_Qwiic_5V_Boost_AP3012K/tree/main/docs) of the [SparkFun RFID USB Reader repository](https://github.com/sparkfun/SparkFun_Qwiic_5V_Boost_AP3012K).

<!-- ### :material-source-pull:&nbsp;Submit a Correction -->
### Submit a Correction

1. With a GitHub account, [fork this repository](https://github.com/sparkfun/SparkFun_Qwiic_5V_Boost_AP3012K/fork).
2. Add your corrections or improvements to the markdown file.
3. File a pull request with your changes, and enjoy making the ~~words~~ ~~worlds~~ world a better place.
	- Once received, the documentation specialist will automatically be notified.
	- We will review your suggested improvements to make sure they are correct and fit within our documentation standards.

## :material-cog:&nbsp;Improve our Hardware Design
All of our designs are open-source! Please help us make it better.

- Our board design files are contained in the [`Hardware` folder](https://github.com/sparkfun/SparkFun_Qwiic_5V_Boost_AP3012K/tree/main/Hardware) of the [SparkFun RFID USB Reader repository](https://github.com/sparkfun/SparkFun_Qwiic_5V_Boost_AP3012K).

<!-- ### :material-source-pull:&nbsp;Submit a Design Enhancement -->
### Submit a Design Enhancement

1. With a GitHub account, [fork this repository](https://github.com/sparkfun/SparkFun_Qwiic_5V_Boost_AP3012K/fork).
2. Add your design augmentation(s)
3. File a pull request with your changes, and enjoy making the ~~words~~ ~~worlds~~ world a better place.
	1. Once received, the engineer in charge of the original design will automatically be notified.
	2. We will review your suggested improvement(s) to verify that they are within our board design standards and meet our product design requirements.
	3. If approved, we will flag these changes for our next board revision. Congrats! 🍻

		!!! info
			Even if your suggestion is accepted, these changes may not be immediately available for purchase. We may have to cycle through our current product inventory first.

## Contributors&nbsp;:clap:
Let's provide some recognition to the contributors for this project!

GitHub Contributors Image
<br>


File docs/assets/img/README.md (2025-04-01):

img directory
====================
This folder should contain the images for the product documentation

## General Images
- `sfe-logo.png` - SparkFun flame logo (favicon)

## Directory
- `graphical_datasheet` - Files for graphical datasheet
- `hookup_guide` - Images for the hookup guide pages
- `qr_code` - QR code images
- `qwiic` - Images for Qwiic Banner

## QR Codes
- [QR code generator](https://qrgenerator.org/)
	- Flame Color: #E0311D
	- Frame Color: #3C464D
- [Remove meta data from svg](https://jakearchibald.github.io/svgomg/)

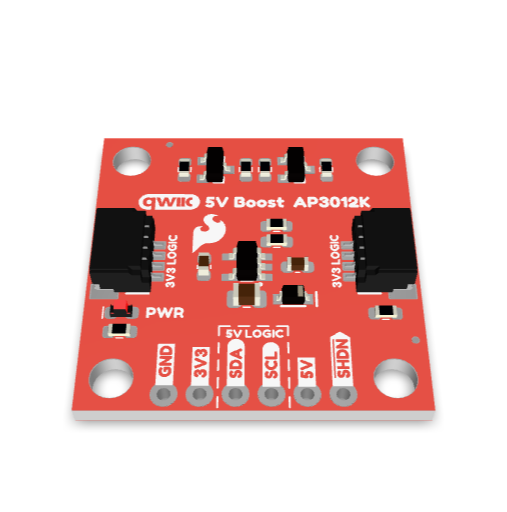
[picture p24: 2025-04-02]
docs/assets/3d_model/poster.png

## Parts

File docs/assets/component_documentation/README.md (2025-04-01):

SparkFun Documentation
=======================

This directory should include any necessary datasheets, example number crunching, etc.

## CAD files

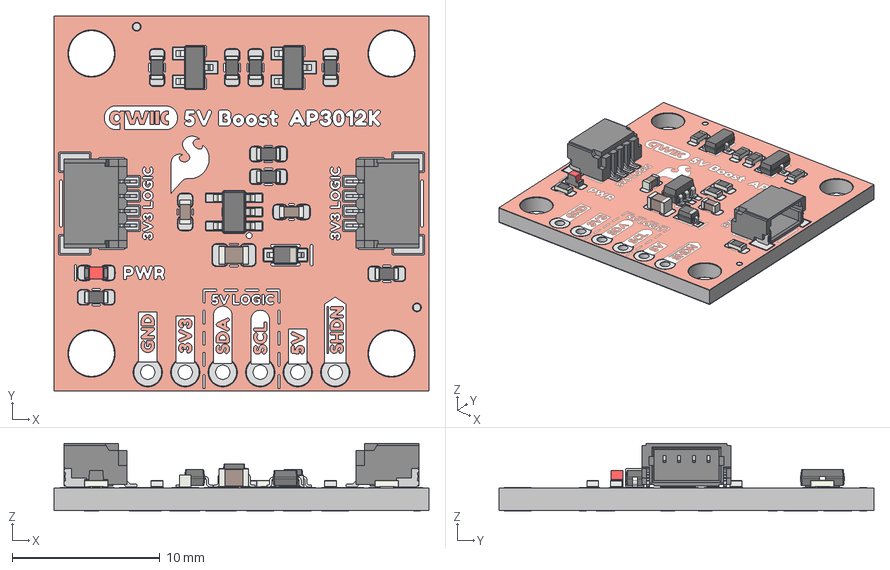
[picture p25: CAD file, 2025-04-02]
docs/assets/3d_model/cad_model.step
25.4 x 25.4 x 4.63 mm
SOT-23-5
LED_0603_1608Metric_Red
Qwiic-Horizontal x 2
C_0603_1608Metric x 2
R_0603_1608Metric x 8
SOT-23 x 2
C_0805_2012Metric
D_SOD-323
SparkFun_Qwiic_5V_Boost_AP3012K_pad
SparkFun_Qwiic_5V_Boost_AP3012K_silkscreen
SparkFun_Qwiic_5V_Boost_AP3012K_soldermask
SparkFun_Qwiic_5V_Boost_AP3012K_PCB

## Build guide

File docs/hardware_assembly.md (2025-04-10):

## Breakout Pins
The [PTH](https://en.wikipedia.org/wiki/Through-hole_technology "Plated Through Hole") pins on the Qwiic 5V Boost are broken out into six 0.1"-pitched pins on the edge of the board. These pins are used to connect a 5V I^2^C device to the [Qwiic connect system](hardware_overview.md#qwiic-connectors).

<div class="grid" markdown>

<div markdown>

Headers are versatile option testing and development.

<figure markdown>
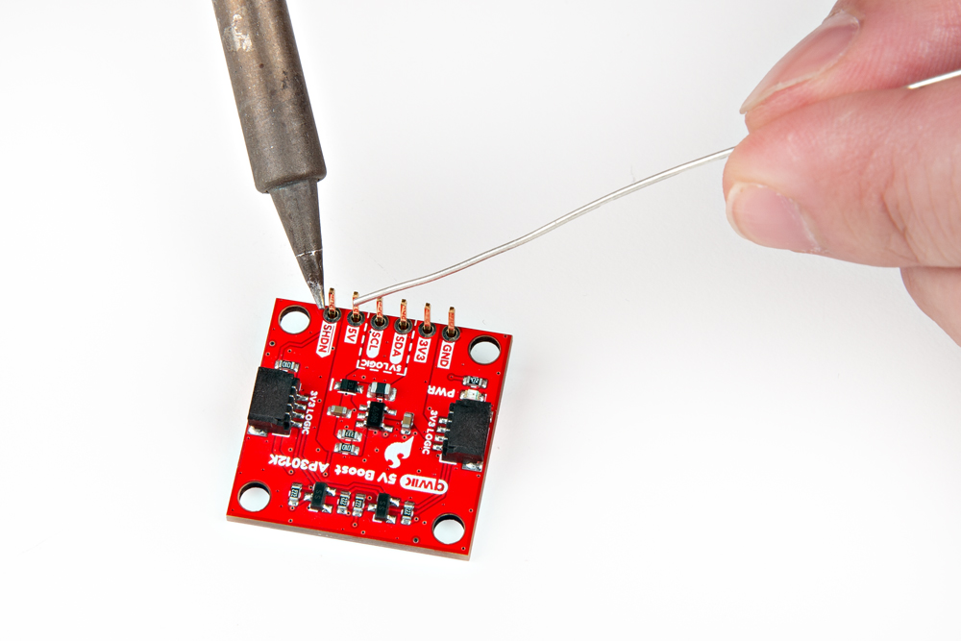
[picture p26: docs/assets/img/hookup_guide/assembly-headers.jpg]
Soldering headers

<figcaption markdown>Soldering headers to the Qwiic 5V Boost.</figcaption>
</figure>

</div>

<div markdown>

Users can also connect a device directly to the board.

<figure markdown>
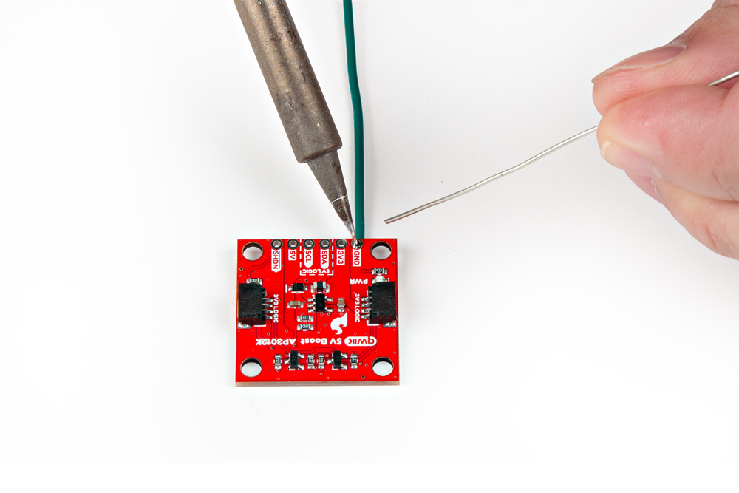
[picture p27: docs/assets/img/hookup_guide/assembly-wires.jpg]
Soldering wires

<figcaption markdown>Soldering wires to the Qwiic 5V Boost.</figcaption>
</figure>

</div>

</div>

???+ tip "New to soldering?"
	If you have never soldered before or need a quick refresher, check out our [How to Solder: Through-Hole Soldering](https://learn.sparkfun.com/tutorials/how-to-solder-through-hole-soldering) guide.

	<div class="grid cards col-4" markdown align="center">

	-   <a href="https://learn.sparkfun.com/tutorials/5">
		<figure markdown>
		Tutorial thumbnail
		</figure>

		---
		
		**How to Solder: Through-Hole Soldering**</a>

	</div>

!!! info "Configuration Options"
	Users will have the following options for connecting a device to the Qwiic 5V Boost:

	<!-- Table of configuration options -->
	--8<-- "./hardware_overview.md:149:166"

	<div class="grid" markdown>

	<div markdown>

	**Power Supply**

	---

	Use either the `5V` or the `3V3` [PTH](https://en.wikipedia.org/wiki/Through-hole_technology "Plated Through-Hole") pins to supply 5V or 3.3V power to the device.

	</div>

	<div markdown>

	**Logic-Level**

	---

	Users can modify the [`3V3`/`5V` jumpers](./hardware_overview.md#jumpers) to configure the logic-level for the `SDA` and `SCL` [PTH](https://en.wikipedia.org/wiki/Through-hole_technology "Plated Through-Hole") pins.

	*By default, the pins are configured to a 5V logic-level.*

	</div>

	</div>

## Qwiic Connector
The simplest method to connect the Qwiic 5V Boost board to a microcontroller and/or other Qwiic devices, is through the Qwiic connector.

<figure markdown>
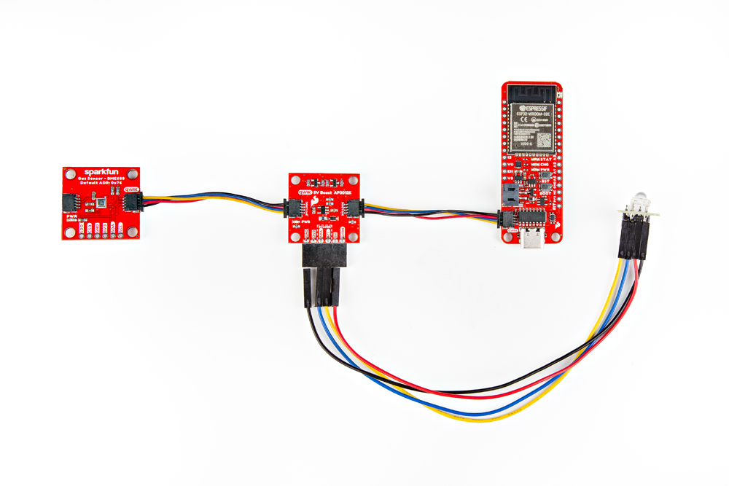
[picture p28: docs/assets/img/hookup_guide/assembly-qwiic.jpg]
Qwiic devices

<figcaption markdown>The Qwiic 5V Boost with a 5V I^2^C RGB LED connected to its PTH pins and daisy-chained with Qwiic cables, though its Qwiic connectors.</figcaption>
</figure>

!!! tip
	The intended design of the Qwiic 5V Boost board was to be utilized with the Qwiic connector system. However, the Qwiic 5V Boost can also be utilized with other interfaces, similar to how the [SparkFun Logic Level Converter - Single Supply](https://www.sparkfun.com/sparkfun-logic-level-converter-single-supply.html) operates. The only difference is its [TTL](https://en.wikipedia.org/wiki/Transistor%E2%80%93transistor_logic "Transistor–Transistor Logic") conversion, which is push-pull and not open-drain.

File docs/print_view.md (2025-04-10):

---
hide:
  - navigation
  - toc
icon: material/printer
---

<!-- Quick Start Guide -->
--8<-- "./quick_start.md"

<!-- Page Break on Print -->
<hr style="page-break-after: always;">

<!-- Hookup Guide -->
--8<-- "./introduction.md::13"

# Hardware Overview
--8<-- "./hardware_overview.md"

# Hardware Assembly
--8<-- "./hardware_assembly.md"

# Troubleshooting Tips
--8<-- "./troubleshooting_tips.md"

# Resources
--8<-- "./resources.md"

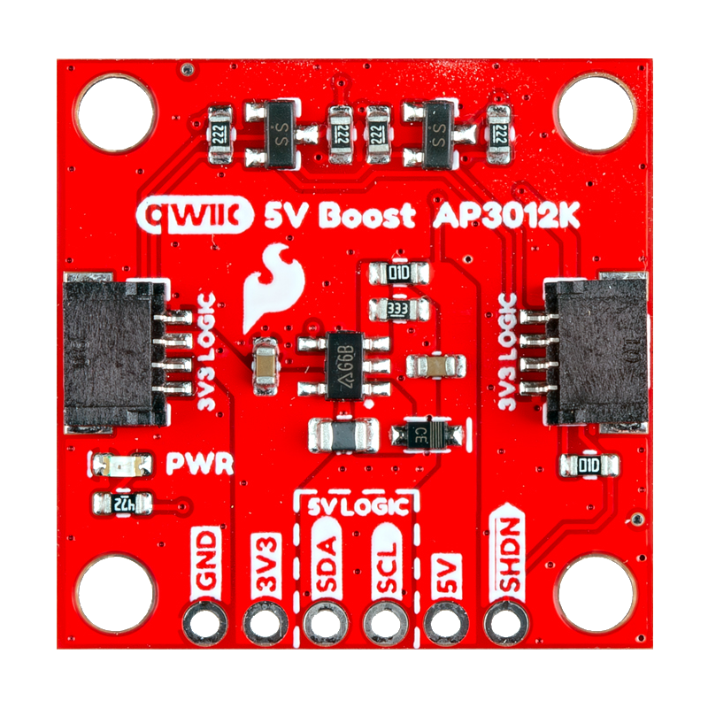
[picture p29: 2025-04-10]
docs/assets/img/hookup_guide/top.png

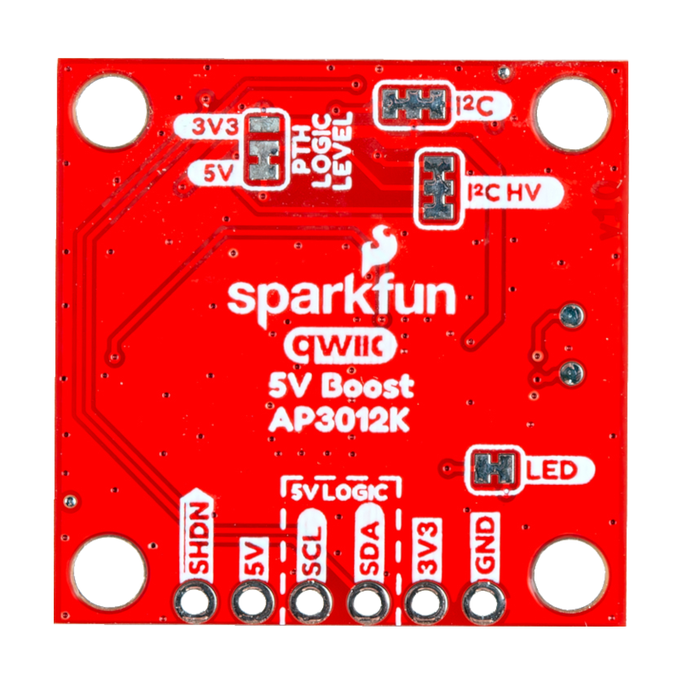
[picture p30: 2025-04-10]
docs/assets/img/hookup_guide/bottom.png

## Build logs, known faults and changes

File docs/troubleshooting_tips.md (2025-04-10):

!!! warning "Need Help?"
	If you need technical assistance or more information on a product that is not working as you expected, we recommend heading over to the [SparkFun Technical Assistance](https://www.sparkfun.com/technical_assistance) page for some initial troubleshooting.

	<center>
	[SparkFun Technical Assistance Page](https://www.sparkfun.com/technical_assistance){ .md-button .md-button--primary }
	</center>

	If you can't find what you need there, the [SparkFun Forums](https://forum.sparkfun.com/index.php) is a great place to search product forums and ask questions.

	!!! info "Account Registration Required"
		If this is your first visit to our forum, you'll need to create a [Forum Account](https://forum.sparkfun.com/ucp.php?mode=register) to post questions.

## Getting Started with the Arduino IDE
This guide assumes users are utilizing the latest version of the Arduino IDE on your desktop. If this is your first time using Arduino IDE, library, or board add-on, please review the following tutorials:

- [Installing the Arduino IDE](https://learn.sparkfun.com/tutorials/installing-arduino-ide)
- [Installing an Arduino Library](https://learn.sparkfun.com/tutorials/installing-an-arduino-library)
- [Installing Board Definitions in the Arduino IDE](https://learn.sparkfun.com/tutorials/installing-board-definitions-in-the-arduino-ide)

## 5V Power Limitation
We recommend users limit the load current on the `5V` output supply voltage to a maximum of ~100mA.

This should not be considered as a limitation dictated by the junction temperature of the AP3012. The limitation is driven by the power supply for the Qwiic connect system and the load being placed on the boost circuit. In order to compensate for the increased current, the supply voltage from the AP3012 boost converter will begin to drop as the current draw increases.

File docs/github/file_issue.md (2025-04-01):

# Did we make a mistake?
Spot something wrong? Please let us know. 

<!-- Technical Assistance Box -->
!!! warning "Need Help?"
	If you need technical assistance or more information on a product that is not working as you expected, we recommend heading on over to the [SparkFun Technical Assistance](https://www.sparkfun.com/technical_assistance) page for some initial troubleshooting. This **Submit Issues** page is not where users should seek assistance.

	<center>
	[SparkFun Technical Assistance Page](https://www.sparkfun.com/technical_assistance){ .md-button .md-button--primary }
	</center>

	If you can't find what you need there, the [SparkFun Forums](https://forum.sparkfun.com) is a great place to search the product forums and ask questions.

	!!! info "Account Registration Required"
		For your first visit to our forum, you'll need to create a [Forum Account](https://forum.sparkfun.com/ucp.php?mode=register) to post questions.

## Discrepancies in the Documentation
All of our documentation can be modified by you! Please help us make it better.

- The documentation files for these pages are contained in the [`docs` folder](https://github.com/sparkfun/SparkFun_Qwiic_5V_Boost_AP3012K/tree/main/docs) of the [SparkFun RFID USB Reader repository](https://github.com/sparkfun/SparkFun_Qwiic_5V_Boost_AP3012K).

### 🔍 Spot something wrong?
If a section of the documentation is incorrect, please [open an issue](https://github.com/sparkfun/SparkFun_Qwiic_5V_Boost_AP3012K/issues) and let us know.

### Do you have a suggested correction?

1. With a GitHub account, [fork this repository](https://github.com/sparkfun/SparkFun_Qwiic_5V_Boost_AP3012K/fork).
2. Add your correction(s) or improvement(s) to the markdown file(s)
3. File a pull request with your changes, and enjoy making the ~~words~~ ~~worlds~~ world a better place.
	- Once received, the documentation specialist will automatically be notified.
	- We will review your suggested improvement(s) to make sure they are correct and fit within our documentation standards.

## Problems in the Hardware Design
All of our designs are open-source! Please help us make it better.

- Our board design files are contained in the [`Hardware` folder](https://github.com/sparkfun/SparkFun_Qwiic_5V_Boost_AP3012K/tree/main/Hardware) of the [SparkFun RFID USB Reader repository](https://github.com/sparkfun/SparkFun_Qwiic_5V_Boost_AP3012K).

### Does something not make sense? 🤔
If part of the design is confusing, please [open an issue](https://github.com/sparkfun/SparkFun_Qwiic_5V_Boost_AP3012K/issues) and let us know.

### Did we forget to include an important function of the board? 🤦
If part of the board's functionality is missing, please [open an issue](https://github.com/sparkfun/SparkFun_Qwiic_5V_Boost_AP3012K/issues) and file a feature request.

!!! tip "Design Considerations"
	Please keep in mind that we may intentionally exclude certain functions of the board to meet our product design requirements.

	- *For example, our Qwiic Micro boards are intended to fit on a small board layout and only use I^2^C communication; therefore, we may not have the SPI and interrupt pins available for users.*

### Do you wish to contribute directly to improving the board design?

1. With a GitHub account, [fork this repository](https://github.com/sparkfun/SparkFun_Qwiic_5V_Boost_AP3012K/fork).
2. Add your design augmentation(s)
3. File a pull request with your changes, and enjoy making the ~~words~~ ~~worlds~~ world a better place.
	1. Once received, the engineer in charge of the original design will automatically be notified.
	2. We will review your suggested improvement(s) to verify that they are within our board design standards and meet our product design requirements.
	3. If approved, we will flag these changes for our next board revision. Congrats! 🍻

		!!! info
			Even if your suggestion is accepted, these changes may not be immediately available for purchase. We may have to cycle through our current product inventory first.

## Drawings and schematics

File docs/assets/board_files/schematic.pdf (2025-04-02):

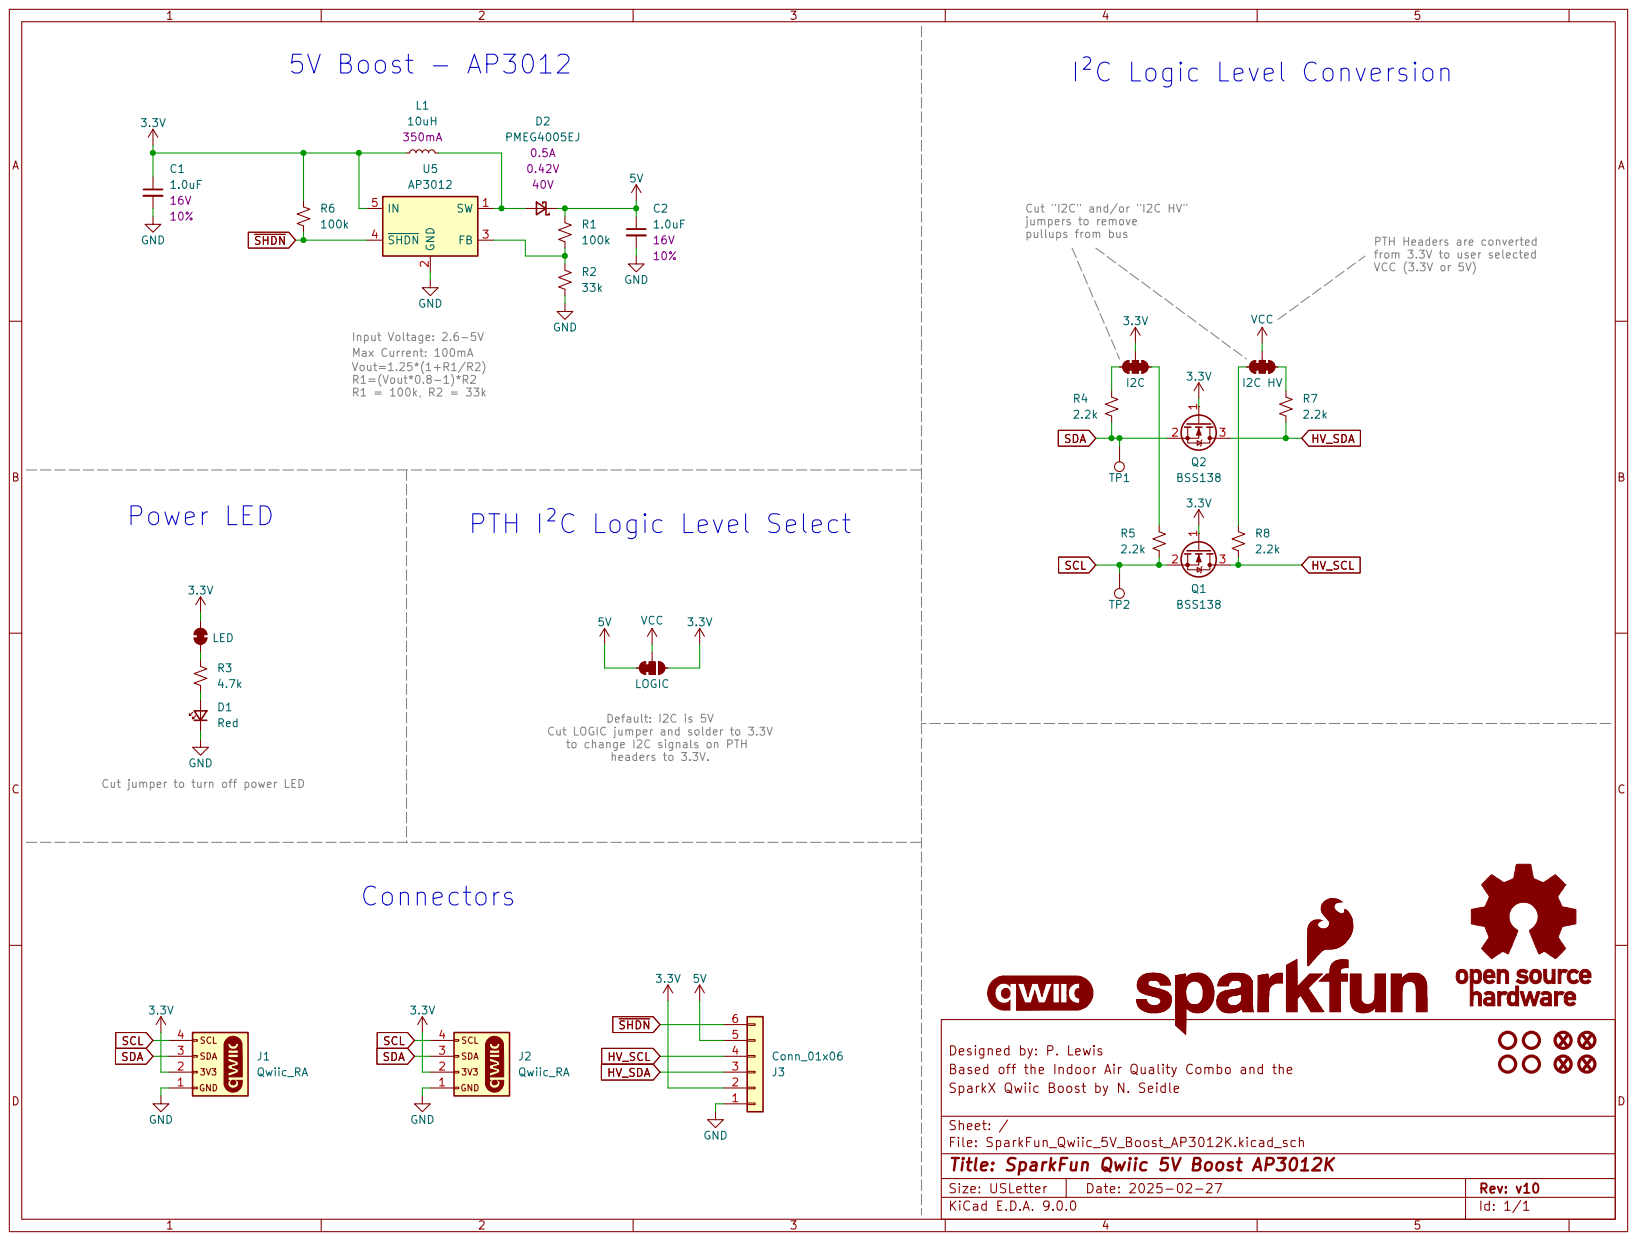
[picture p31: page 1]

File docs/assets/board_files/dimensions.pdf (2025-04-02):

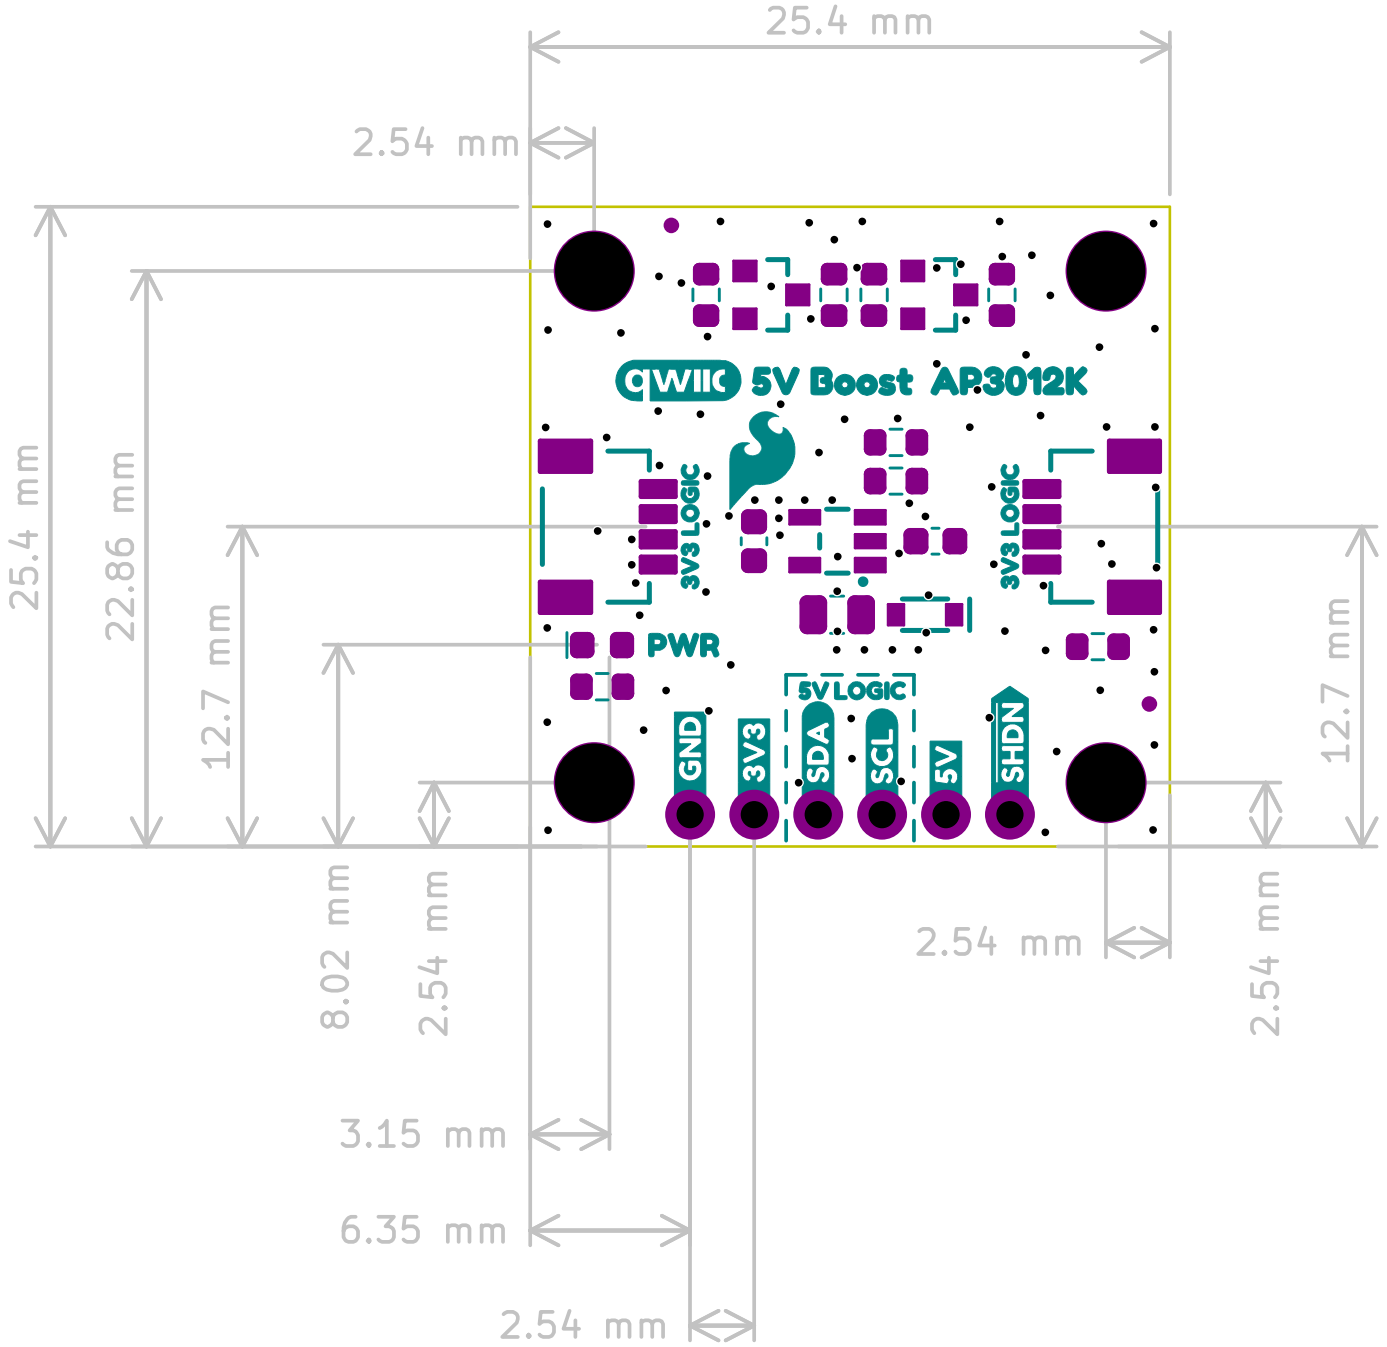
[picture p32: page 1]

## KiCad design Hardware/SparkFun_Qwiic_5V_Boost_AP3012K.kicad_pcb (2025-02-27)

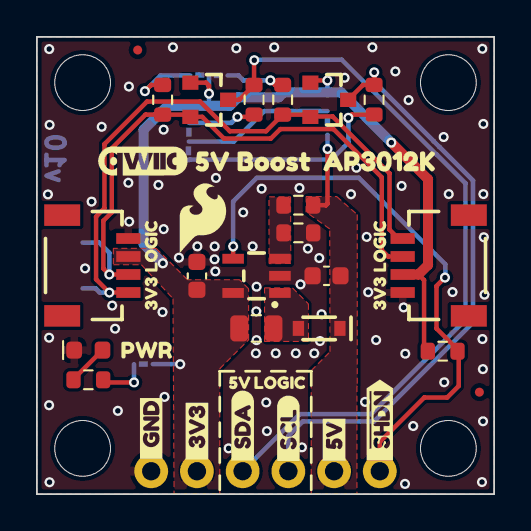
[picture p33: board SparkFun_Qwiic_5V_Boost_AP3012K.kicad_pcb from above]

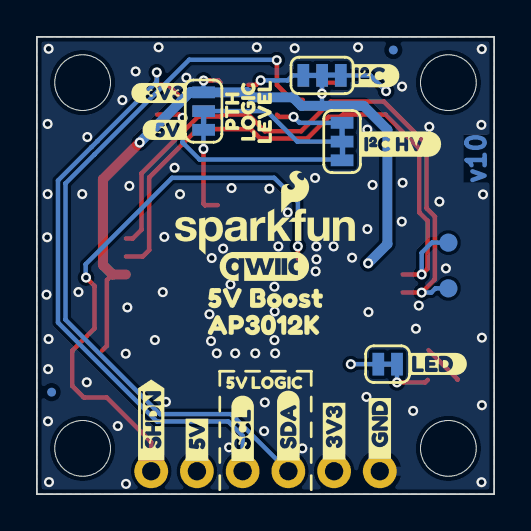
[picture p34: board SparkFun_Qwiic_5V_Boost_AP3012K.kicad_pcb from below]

Board: 2 copper layers, 25.4 x 25.4 mm, 65 parts (26 on the bottom side), 17 nets.

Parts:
C1, C2: 1.0uF; C_0603_1608Metric
D1: Red; LED_0603_1608Metric_Red
D2: PMEG4005EJ; SOD-323
FID1, FID2, FID3, FID4: Fiducial_0.5mm; Fiducial_0.5mm_Mask1mm
G4: OSHW_Logo; Creative_Commons_License
J1, J2: Qwiic_RA; JST_SMD_1.0mm-4_RA
J3: Conn_01x06; 1x06
JP1: LED; Jumper_2_NC_Trace
JP2: I2C; Jumper_3_NC-2_Trace
JP3: LOGIC; Jumper_3_NC-1_Trace
JP4: I2C HV; Jumper_3_NC-2_Trace
L1: 10uH; C_0805_2012Metric
Q1, Q2: BSS138; SOT23-3
R1, R6: 100k; R_0603_1608Metric
R2: 33k; R_0603_1608Metric
R3: 4.7k; R_0603_1608Metric
R4, R5, R7, R8: 2.2k; R_0603_1608Metric
ST1, ST2, ST3, ST4: Standoff
TP1, TP2: 1.0mm; TestPoint-1.0mm
U5: AP3012; SOT23-5
kibuzzard-65A8A8B4: G***; kibuzzard-65A8A8B4
kibuzzard-65A8B05B: G***; kibuzzard-65A8B05B
kibuzzard-67A51B2D: G***; kibuzzard-67A51B2D
kibuzzard-67A51B3F: G***; kibuzzard-67A51B3F
kibuzzard-67A51B57: G***; kibuzzard-67A51B57
kibuzzard-67A51CFE, kibuzzard-67A51CFE#2: G***; kibuzzard-67A51CFE
kibuzzard-67A5195F: G***; kibuzzard-67A5195F
kibuzzard-67A51507, kibuzzard-67A51507#2: G***; kibuzzard-67A51507
kibuzzard-67AB7F1B: G***; kibuzzard-67AB7F1B
kibuzzard-67AB7F2D: G***; kibuzzard-67AB7F2D
kibuzzard-67BF5EEE, kibuzzard-67BF5EEE#2: G***; kibuzzard-67BF5EEE
kibuzzard-67BF5EF7, kibuzzard-67BF5EF7#2: G***; kibuzzard-67BF5EF7
kibuzzard-67BF5F1D, kibuzzard-67BF5F1D#2: G***; kibuzzard-67BF5F1D
kibuzzard-67BF7C99: G***; kibuzzard-67BF7C99
kibuzzard-67BF7CAB: G***; kibuzzard-67BF7CAB
kibuzzard-67BF7CFE: G***; kibuzzard-67BF7CFE
kibuzzard-67BF7D5E: G***; kibuzzard-67BF7D5E
kibuzzard-67BF7D12: G***; kibuzzard-67BF7D12
kibuzzard-67BF7D85: G***; kibuzzard-67BF7D85
kibuzzard-67BF7EBF: G***; kibuzzard-67BF7EBF
kibuzzard-67BF7ED9: G***; kibuzzard-67BF7ED9
kibuzzard-67BF7F2F: G***; kibuzzard-67BF7F2F
kibuzzard-67BF7F4D: G***; kibuzzard-67BF7F4D
kibuzzard-67BF7F7D: G***; kibuzzard-67BF7F7D
kibuzzard-67BF7F13: G***; kibuzzard-67BF7F13
kibuzzard-67C0A4F9: G***; kibuzzard-67C0A4F9

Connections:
3.3V: C1.1, J1.2, J2.2, J3.2, JP1.2 (B), JP2.2 (B), JP3.3 (C), L1.1, Q1.1 (G), Q2.1 (G), R6.2, U5.5 (IN)
5V: C2.1, D2.1 (K), J3.5, JP3.1 (A), R1.2
GND: C1.2, C2.2, D1.1 (K), J1.1, J2.1, J3.1, R2.2, U5.2 (GND)
HV_SCL: J3.4, Q1.3 (D), R8.2
HV_SDA: J3.3, Q2.3 (D), R7.2
unnamed: D1.2 (A), R3.1
unnamed: D2.2 (A), L1.2, U5.1 (SW)
unnamed: JP1.1 (A), R3.2
unnamed: JP2.1 (A), R5.1
unnamed: JP2.3 (C), R4.2
unnamed: JP4.1 (A), R7.1
unnamed: JP4.3 (C), R8.1
unnamed: R1.1, R2.1, U5.3 (FB)
SCL: J1.4, J2.4, Q1.2 (S), R5.2, TP2.1
SDA: J1.3, J2.3, Q2.2 (S), R4.1, TP1.1
VCC: JP3.2 (B), JP4.2 (B)
~SHDN: J3.6, R6.1, U5.4 (~SHDN)

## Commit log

2025-02-06 layout work
    [SparkFun_Qwiic_5V_Boost_AP3012K.kicad_pcb, SparkFun_Qwiic_5V_Boost_AP3012K.kicad_sch]
2025-02-07 silk adjustments - add flame logo to top
    [SparkFun_Qwiic_5V_Boost_AP3012K.kicad_pcb]
2025-02-10 checklist run eng
    -sch cleanup
    -changed red led bias resistor to 4.7k
    -adjusted thermal reliefs/spokes on power PTH headers (GND, 3V3, 5V)
    -wire stubs removed
    -dimensions added
    [SparkFun_Qwiic_5V_Boost_AP3012K.kicad_pcb, SparkFun_Qwiic_5V_Boost_AP3012K.kicad_sch]
2025-02-13 design review changes part 1
    -changed silk for logic jumper to PTH LOGIC LEVEL
    -Added dashed lines around ADS/SCL PHT headers to show these logic levels are set by LOGIC jumper.
    -Changed Value of JP3 to LOGIC
    -un-bolded sch block title texts, switched to blue color
    -aligned PWR silk label with LED perfectly
    [SparkFun_Qwiic_5V_Boost_AP3012K.kicad_pcb, SparkFun_Qwiic_5V_Boost_AP3012K.kicad_sch]
2025-02-14 Review part 2
    -Update layer names
    -changed material to TG135
    -Centered (roughly) the board design in the frame
    -set my grid/drill origin points to bottom left corner of PCB edge cut (aka dimensional outline).
    -updated measures
    [SparkFun_Qwiic_5V_Boost_AP3012K.kicad_pcb]
2025-02-26 more design review feedback
    -SCH, changed all flags to inputs
    -BRD, re-routed HV I2C lines to avoid coupling with 3V3 trace
    -BRD, adjusted 5V and SHDN routing for less vias/more-direct
    -BRD, adjusted SDA/SCL routing away from right qwiic connector to provide more clearance from mask.
    -BRD, removed and moved GND vias to avoid bottom silk
    -BRD, scooted GND vias near SDA/SCL header pins to avoid bulging in the pours.
    -BRD, updated layers to new standards
    [SparkFun_Qwiic_5V_Boost_AP3012K.kicad_pcb, SparkFun_Qwiic_5V_Boost_AP3012K.kicad_sch]
2025-02-26 silk update logic level labels
    -added 3v3 logic level labels to qwiic connectors
    -changed PTH header silk to show default 5V logic level
    [SparkFun_Qwiic_5V_Boost_AP3012K.kicad_pcb]
2025-02-26 buzzard label adjustments
    -extended left side spacing of PTH buzzard labels to 6mils
    -positioned them so they clear the PTH header plastic molding courtyard
    -snapped them all to a 6.25mils grid.
    [SparkFun_Qwiic_5V_Boost_AP3012K.kicad_pcb]
2025-02-26 moving parts onto 12.5mil grid
    -moved parts (except the boost circuit stuff) onto the 12.5 mil grid.
    [SparkFun_Qwiic_5V_Boost_AP3012K.kicad_pcb]
2025-02-27 I2C HV pullup jumper
    -added pullup jumper for I2C HV
    -Updated D2 to latest footprint
    [SparkFun_Qwiic_5V_Boost_AP3012K.kicad_pcb, SparkFun_Qwiic_5V_Boost_AP3012K.kicad_sch]
2025-02-27 final feedback
    -BRD - turned on all layers to visible
    -SCH - changed note about max current to 100mA
    -nudged SDA trace to remove a bump
    [SparkFun_Qwiic_5V_Boost_AP3012K.kicad_pcb, SparkFun_Qwiic_5V_Boost_AP3012K.kicad_sch]
2025-02-27 updated attribution and issue date
    [SparkFun_Qwiic_5V_Boost_AP3012K.kicad_pcb, SparkFun_Qwiic_5V_Boost_AP3012K.kicad_sch]
2025-02-27 added 2 test points
    -added test points for 3V3 logic level SDA/SCL
    [SparkFun_Qwiic_5V_Boost_AP3012K.kicad_pcb, SparkFun_Qwiic_5V_Boost_AP3012K.kicad_sch]
2025-04-02 Add design files and 3D models
    [cad_model.step]

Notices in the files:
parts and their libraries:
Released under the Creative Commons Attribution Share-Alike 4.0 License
